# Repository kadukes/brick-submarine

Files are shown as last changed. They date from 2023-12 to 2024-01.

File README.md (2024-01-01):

# Brick Submarine

This project contains a collection of circuit python scripts 
used in a raspberry pi in order to run a small autonomous 
underwater vehicle. This project is currently work in progress 
and not finished by far. Main parts of the project were 
inspired by a series of blog entries from a finnish creator 
called "Brick Experiment Channel" which can be found here: 
https://brickexperimentchannel.wordpress.com/. I will refer 
to this blog along the explanations in this readme.

My goal is to adapt the ideas in that blog and to overcome 
the limits it has by its current design. 

## Part 1: Building the hull

The hull of the submarine basically requires 
the same parts as those in the blog i.e. we also use an 
acrylic cylinder for the basic shape. 

However, the end caps are not assembled from acrylic parts, 
but printed using a 3D printer. The mesh-files for these can be 
found in the `resources\prints` directory.

* `cap_head.stl`: This is the model of the front cap. It is 
    open at the front so that an acrylic glass pane can be 
    glued into the front. I used silicone for this. The cap 
    also has two grooves in which you can insert two sealing 
    rings. I took this idea from this Thingiverse project: 
    https://www.thingiverse.com/thing:4638848

    _Note_: We recommend the purchase of sealing rings. A 
    rubber seal is used in the blog, which is then glued 
    together to form a ring. However, this can mean that the 
    sealing function is not maintained satisfactorily.
* `cap_tail.stl`: This is the model of the rear cap. Unlike 
    the front cap, it is closed and contains three holes: two 
    plug connections for hoses and a central hole for cables.
* `sonar_mount.stl`: This part ensures that the sonar 
    sensor has a flat mount for the round surface of the 
    cylinder. 

For the remaining construction steps, please refer to the 
individual blog entries. These are explained there simply and 
clearly. 

Here is a (non-exhaustive) list of the additional materials 
required:
* Weights (we recommend tungsten, even if it is expensive. 
    Alternatively, you can use lead weights and strap them 
    around the cylinder)
* A syringe (it should hold approx. 50 to 60 ml)
* A drone propeller
* Neodymium magnets (suitable for the holes of LEGO® 3649 and 
    3648 gear wheels or similar)
* UHMW PE film tape

## Part 2: Building the mechanics

The mechanics of the submarine are made entirely of LEGO®. 
You can find an LDraw file and a parts list in the `resources/lego` 
directory. 

Interested readers can draw further inspiration from the blog entries 
and videos. 

## Part 3: Electronics

The picture below shows the circuit between the Raspberry Pi 
Zero 2 W and the rest of the electronics

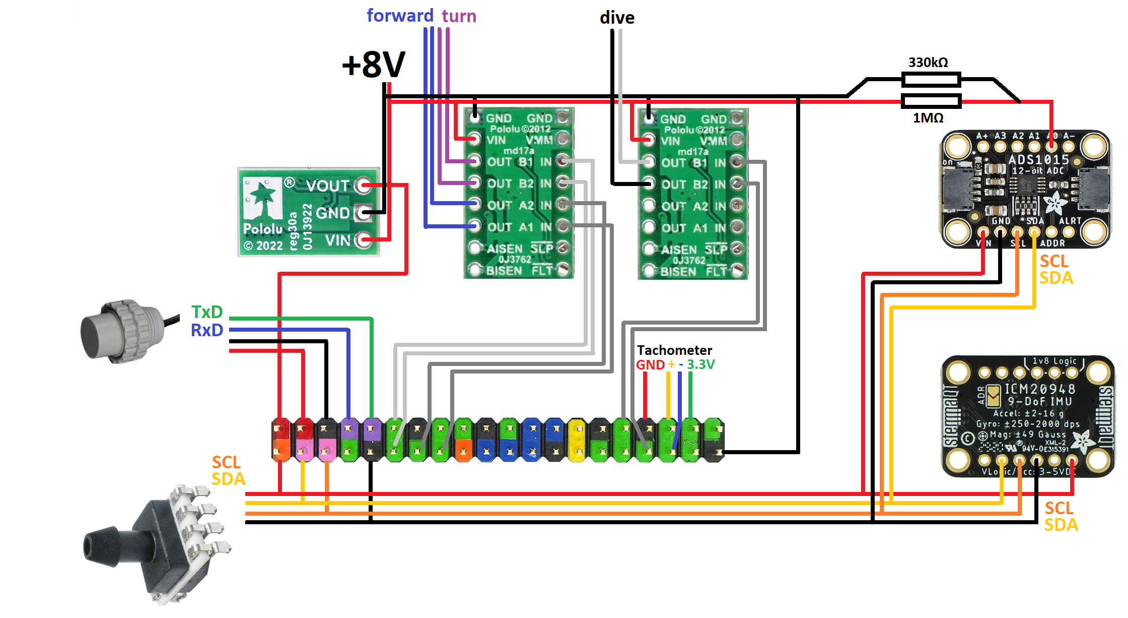
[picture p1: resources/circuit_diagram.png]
circuit diagram


Here is a (non-exhaustive) list of the electronic components 
required:
* Battery source (e.g. LEGO® 8878 Rechargeable
    Battery Box)
* Voltage regulator (e.g. Pololu 2123 S7V8F5 5V)
* 2x Motor driver (e.g. Pololu 2130 DRV8833 Dual H-bridge)
* Sonar sensor (should be waterproof, e.g. SEN0598)
* Pressure sensor (e.g. Honeywell SSCMANV030PA2A3 2 bar)
* 9-Axis Digital motion processor (e.g. ICM-20948)
* Analog digital converter (e.g. COM-KY053ADC)

## Part 4: Software

The software is located in the src directory. It is currently 
in an unusable state. We are continuously developing the code. 
If you would like to contribute, please open an issue for this 
project.

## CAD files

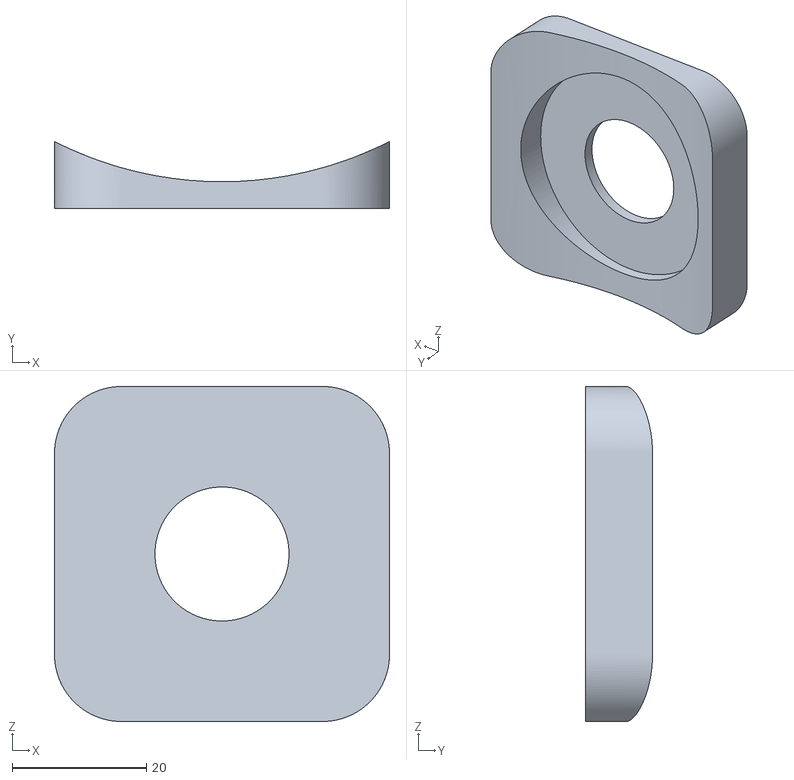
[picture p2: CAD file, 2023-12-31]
resources/prints/sonar_mount.stl
50.0 x 10.0 x 50.0

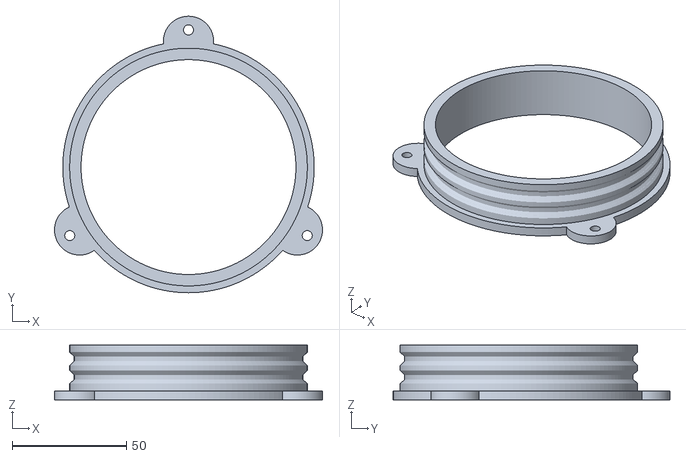
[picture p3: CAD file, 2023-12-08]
resources/prints/cap_head.stl
117.3 x 121.0 x 24.0

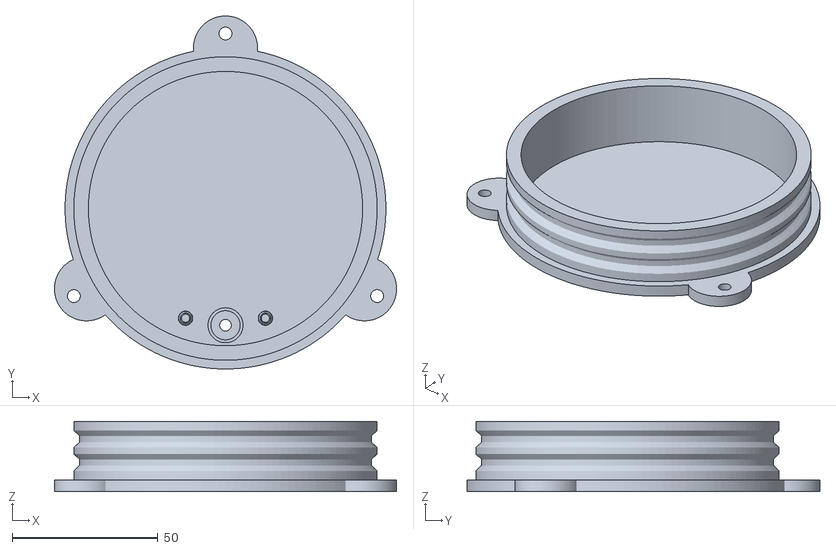
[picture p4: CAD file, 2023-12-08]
resources/prints/cap_tail.stl
117.3 x 121.0 x 24.0

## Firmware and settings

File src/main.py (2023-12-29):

from threading import Thread
import logging
from time import sleep

import emergency
from sensor import gyro
from sensor import pressure
from sensor import sonar

logging.basicConfig(format='[%(levelname)s] - %(asctime)s - %(message)s', encoding='utf-8', level=logging.DEBUG)
logger = logging.getLogger(__name__)

logger.info("Begin testing sensors")
gyro.calibrate()
# gyro.load_calibration()

Thread(target=gyro.gyro_integrator).start()  # integrate gyro data
Thread(target=pressure.filter_pressure).start()  # listen to pressure signals and filter them
Thread(target=sonar.sonar_listener).start()  # listen to sonar signals

Thread(target=emergency.voltage_monitor).start()  # monitor battery voltage and adc sensor status
Thread(target=emergency.gyro_monitor).start()  # monitor gyro sensor status
Thread(target=emergency.pressure_monitor).start()  # monitor pressure sensor status
Thread(target=emergency.sonar_monitor).start()  # monitor sonar sensor status

while True:
    logger.info("="*100)

    logger.info("Acceleration [m/s²]: ({}, {}, {})".format(*gyro.get_acceleration()))
    logger.info("Velocity [m/s]: ({}, {}, {})".format(*gyro.get_velocity()))
    logger.info("Displacement [m]: ({}, {}, {})".format(*gyro.get_displacement()))
    logger.info("Angular velocity [rads/s]: ({}, {}, {})".format(*gyro.get_angular_velocity()))
    logger.info("Angular rotation [rads]: ({}, {}, {})".format(*gyro.get_rotation()))
    logger.info("Magnetometer [µT]: ({}, {}, {})".format(*gyro.get_magnetometer()))

    logger.info("Pressure [psi]: {}".format(pressure.get_pressure()))
    logger.info("Bottom distance [mm]: {}".format(sonar.get_sonar_data()))

    sleep(1)

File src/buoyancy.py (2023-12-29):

from time import sleep
import logging
from gpiozero import PWMOutputDevice

from sensor import tacho


logger = logging.getLogger(__name__)

motor_up = PWMOutputDevice(12)  # pin for motor control 1
motor_down = PWMOutputDevice(13)  # pin for motor control 2

motor_up.value = 0
motor_down.value = 0


def move(target_position):
    """
    dive or surface by controlling the syringe motor unit

    targetPosition -- [0, SYRINGE_TACHOMETER_COUNT_TOTAL] the target position to move the syringe to
                      (with an error by SYRINGE_BACKLASH)
    """
    if target_position < 0 or target_position > tacho.SYRINGE_TACHOMETER_COUNT_TOTAL:
        logger.error("Cannot move to syringe position {}".format(target_position))
        return

    if target_position < tacho.current_tachometer_count:
        # Experimental result: 18000>> | drift: 200<<
        tacho.current_tachometer_count = (tacho.current_tachometer_count +
                                          int(200 * (tacho.current_tachometer_count - target_position) / 18000))

    while abs(target_position - tacho.current_tachometer_count) > tacho.SYRINGE_PRECISION:
        if target_position < tacho.current_tachometer_count:
            motor_down.value = 0
            motor_up.value = 1
        elif target_position > tacho.current_tachometer_count:
            motor_up.value = 0
            motor_down.value = 1
        sleep(0.1)
    motor_up.value = 0
    motor_down.value = 0
    tacho.write_tachometer_position()  # TODO uncouple this from movement


def move_relative(delta_count):
    """
  WARNING: use this only for debugging!
  move motor relative to current position

  deltaCount -- [int] the relative position from current position to move to
  """
    target_position = tacho.current_tachometer_count + delta_count
    while abs(target_position - tacho.current_tachometer_count) > tacho.SYRINGE_PRECISION:
        if target_position < tacho.current_tachometer_count:
            motor_down.value = 0
            motor_up.value = 1
        elif target_position > tacho.current_tachometer_count:
            motor_up.value = 0
            motor_down.value = 1
        sleep(0.1)
    motor_up.value = 0
    motor_down.value = 0
    tacho.write_tachometer_position()  # TODO uncouple this from movement

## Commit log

2023-11-25 add pressure sensor code
2023-11-26 reading adc sensor data
2023-11-26 read gyro sensor data
2023-11-26 read all sensor data and make the sensor directory a python module
2023-11-26 implement buoyancy, navigation and power unit
2023-12-04 implement accelerometer data with filters; add test file;add .gitignore file; enable logging
2023-12-06 fix integral calculation in accelerometer and namings
    [gyro.py, test_sensor.py]
2023-12-06 make calibration values negative to avoid too many function calls
    [gyro.py]
2023-12-06 apply filter and rounding precision while reading sensor data; implement gyroscope readings
2023-12-06 add requirements; finish sensor tests; gyro is still inaccurate...
2023-12-06 add mesh models for submarine parts
    [cap_head.stl, cap_tail.stl, sonar_admission.stl]
2023-12-06 add circuit diagram
2023-12-06 fix resistor values and typo in circuit diagram
2023-12-06 Add files via upload
    update circuit diagram
2023-12-08 make cable mount a little bigger
    [cap_head.stl, cap_tail.stl]
2023-12-08 fix export error
    [cap_head.stl, cap_tail.stl]
2023-12-09 round values from sensors
2023-12-09 implement battery voltage monitor
2023-12-09 add monitoring thread for gyro sensor and first naive emergency surface method
2023-12-09 add monitor for pressure sensor
2023-12-09 apply filter to magnetometer
2023-12-09 add monitor for sonar sensor
2023-12-09 set magnetometer rate
2023-12-29 use new sonar sensor
2023-12-29 add serial to requirements, add thread for filtering pressure and monitoring sonar, detect sonar faults, fix emergency monitoring logic
    [emergency.py, main.py, sonar.py]
2023-12-29 change name of new sonar sensor used
2023-12-31 add new sonar mount
    [sonar_mount.stl]
2024-01-01 add ldraw and parts list for lego
    [cap_head.stl, cap_tail.stl, sonar_admission.stl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]
2024-01-01 add new sonar sensor to circuit diagram
